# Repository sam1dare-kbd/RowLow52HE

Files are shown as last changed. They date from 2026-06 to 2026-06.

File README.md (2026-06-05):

# RowLow52HE

RowLow52HE is a 50% Hall-effect keyboard based on the [HE60](https://github.com/peppapighs/HE60) project. <br>

RowLow52HEは、HE60プロジェクトをベースにして設計した50%の磁気キーボードです。<br>
<br>

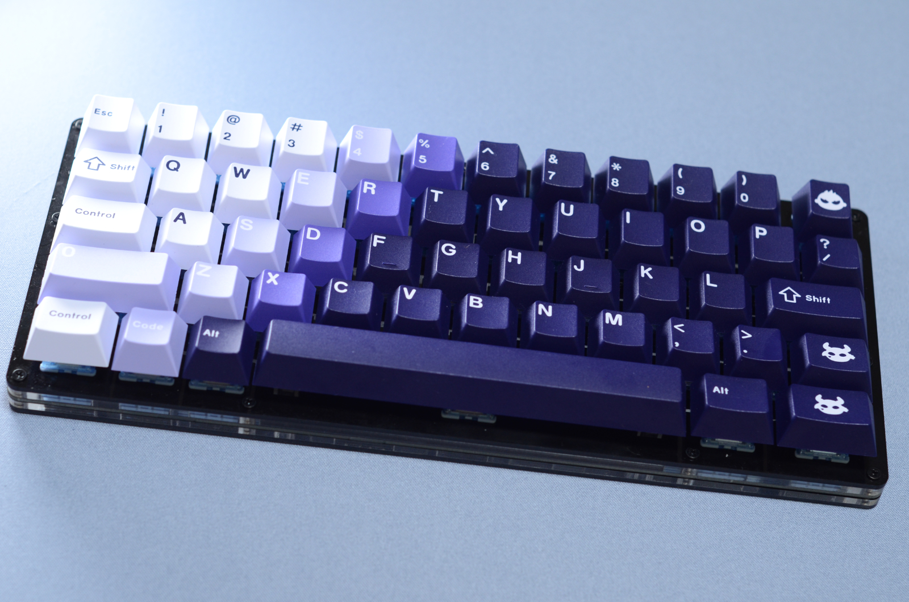
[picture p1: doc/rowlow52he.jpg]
RowLow52HE


---

# Build Guide  

https://note.com/sam1dare/n/naa1372ecf801 <br>
(Japanese text only.)

---

# Important Notes 

This keyboard uses magnetic sensors and may become warm around the MCU during operation. <br>
If you notice abnormal heat generation or unexpected behavior, stop using the device and inspect it before further use.<br><br>

本キーボードは磁気センサーを使用しているため、使用環境によってはMCU周辺が温かくなる場合があります。<br>
異常な発熱や動作不良が発生した場合は、使用を中止してください。

---

# HE60 (Original Project)

Below is the original README from the HE60 project, which this keyboard is based on.

---

# HE60

HE60 is a 60% Hall-effect keyboard PCB with 8kHz polling rate, a split spacebar and Tsangan layout support.

## Features

- Support for GH60 tray mount cases e.g., KBDfans Tofu60 Redux, and KBDfans Holy60.
- Support for gummy O-ring mount cases **if the USB-C port is not soldered** e.g., Bakeneko60, and SingaKBD Unikorn (required 10mm JST cable).
- [libhmk](https://github.com/peppapighs/libhmk) firmware.
- [hmkconf](https://hmk.prasertsuk.com) web-based configurator.

## Disclaimer

- The PCB requires standoffs to be mounted to the switch plate. The mounting points are **not compatible** with other available plates e.g., GEON Venom60 7U plate. HE60 v1 plate **is not compatible** with this PCB.

## Supported Layouts

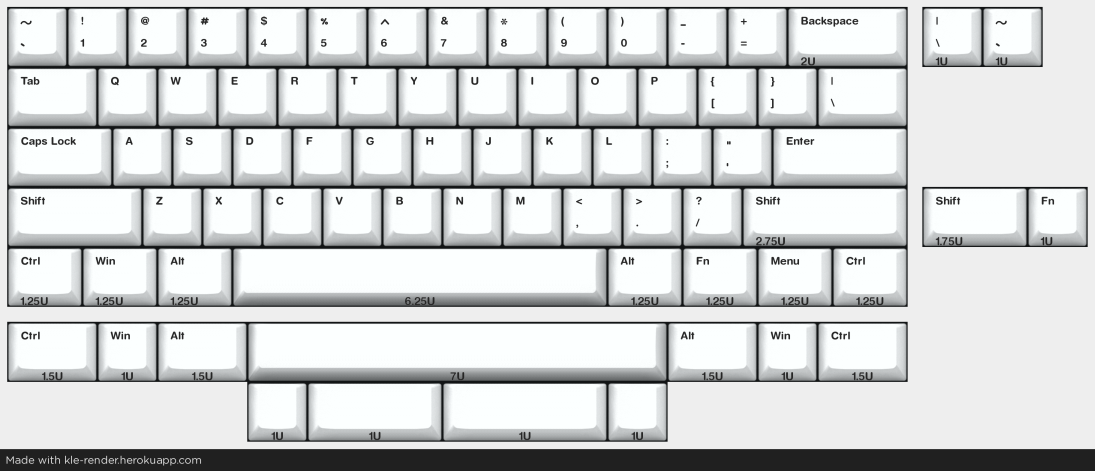
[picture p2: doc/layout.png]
Layouts


## Fabrication

The following files are required:

- BOM (Bill of Materials): Contains the list of components required to build the PCB.
- Pick and Place: Contains the placement of the components on the PCB.
- Gerber: Contains the PCB design files for fabrication.

Note that the components in the BOM are all mounted on the bottom side of the PCB, and are based on the available components in JLCPCB at the time of writing. You may need to adjust the components based on your preference or availability. For the JST connector (labeled `JST_SH`), I used `WAFER-SH1.0-4PWB` offered by JLCPCB. **Make sure to deselect the USB-C port when choosing the components to solder if you are using the gummy O-ring version.**

You may change the Hall-effect sensors during the component selection based on your preference, and availability. Different sensors require different calibration values, which can be adjusted using the web-based configurator. Here are some options that I have used:

- GH39FKSW (Cheapest)
- MT9102ET
- SS39ET
- DRV5055A3
- OH49E-S (Discontinued)

The fabrication files above are available [here](https://github.com/peppapighs/HE60/releases).

## Build Guide

The following items are required to build the PCB:

- PCB
- Switch plate (DXF file available [here](/plate.dxf). You may need to use less flexible materials such as aluminum or FR4 to prevent the switch at the top right corner from popping out if you use the alternative backspace layout. If you would like to manufacture FR4 plate along with the PCB, you can find the GERBER file for the plate [here](https://github.com/peppapighs/HE60/releases).)
- Magnetic switches (e.g., GEON Raw HE, Gateron Magnetic Jade, Duhuk Core HE, etc.)
- Stabilizers (**Clip-in stabilizers are required for the gummy O-ring version**)
- M2 3.5mm standoffs x8
- M2 3mm flat head screws x16

1. Install the stabilizers to the PCB.

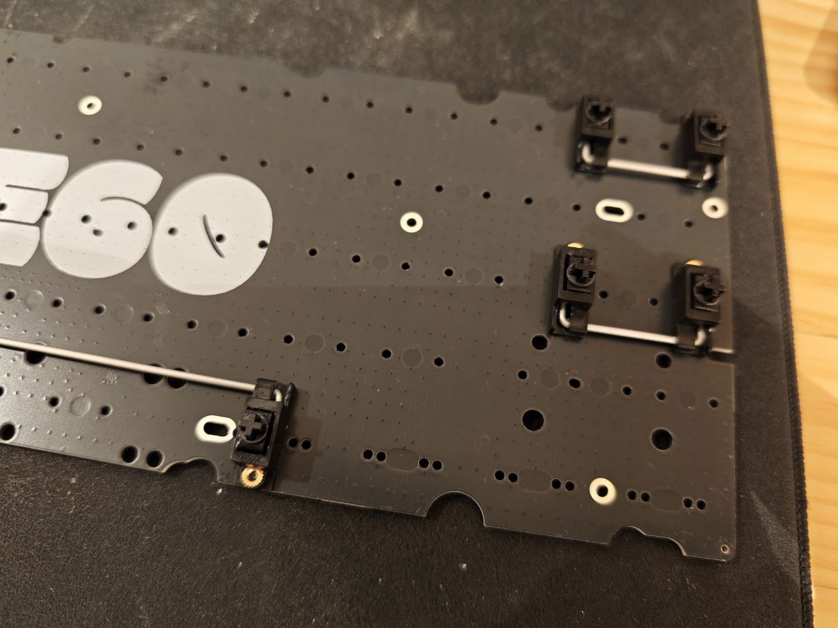
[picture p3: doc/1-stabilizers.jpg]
Stabilizers


2. Attach the standoffs to the PCB using the M2 screws.

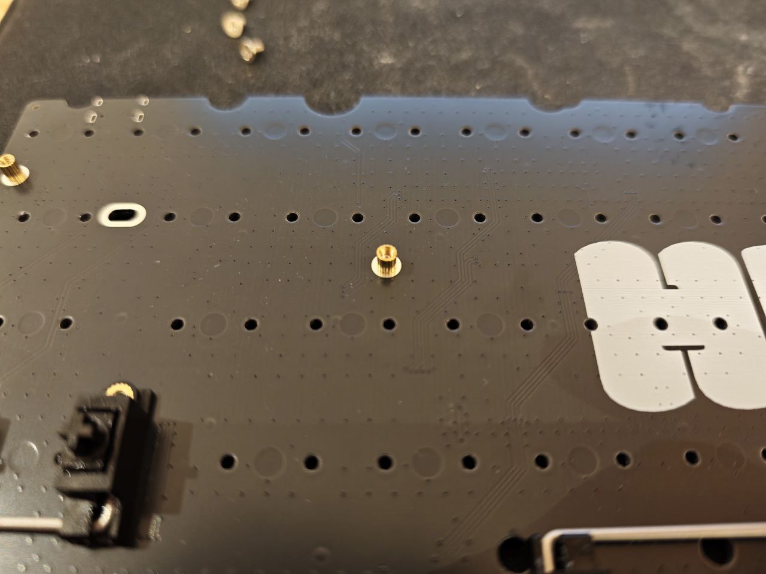
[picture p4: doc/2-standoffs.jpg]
Standoff


3. Install the switches to the plate. Assemble the plate and PCB together. Press the PCB against the plate to make sure the switches are seated properly. Screw the standoffs to the plate using the rest of the M2 screws.

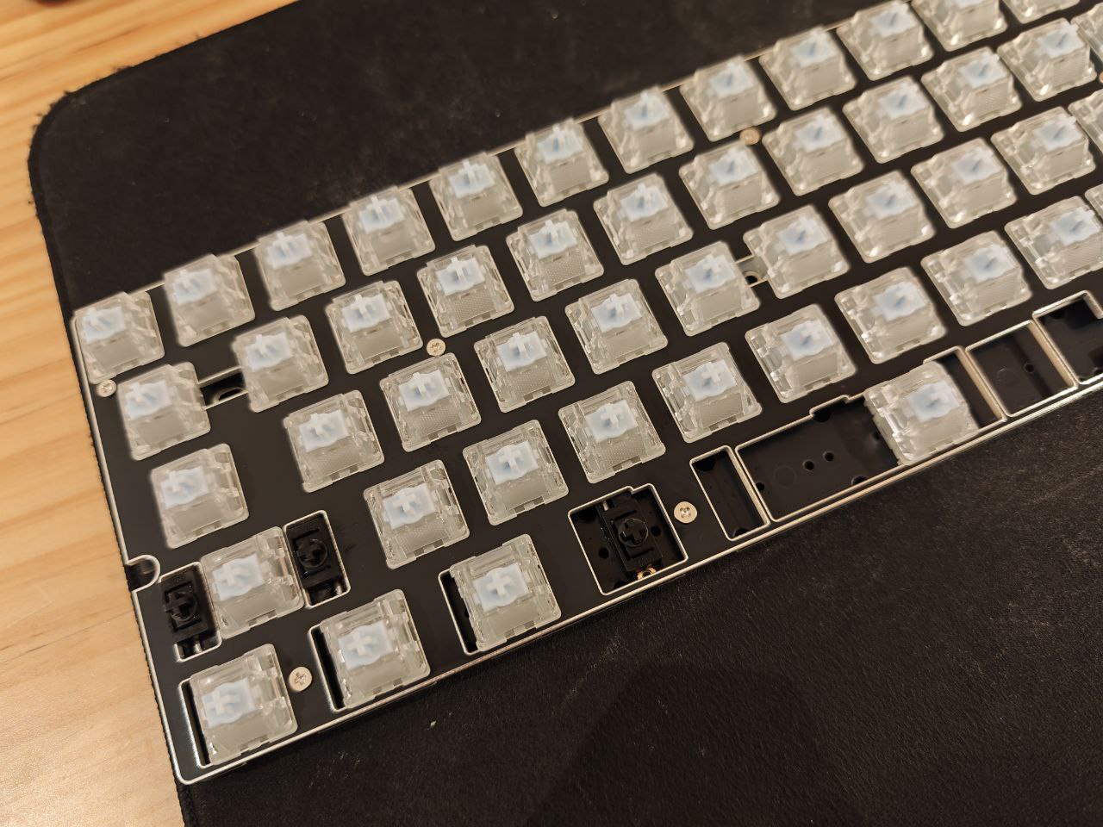
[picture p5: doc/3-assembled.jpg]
Assembled


4. Install the PCB into the case.

Case with keycaps

## Firmware

Head to [libhmk](https://github.com/peppapighs/libhmk/releases) for a pre-compiled firmware. The firmware can be flashed using DFU mode, which can be entered by holding the BOOT button before plugging in. You may need to install the DFU bootloader driver using Zadig. See [libhmk](https://github.com/peppapighs/libhmk) for more information for firmware flashing instructions.

## Acknowledgements

- Xelus from AEBoards for reviewing the PCB design and providing feedback.
- Keyboard Atelier community for supporting the project.

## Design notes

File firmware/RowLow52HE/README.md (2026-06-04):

# RowLowHE52

 RowLowHE52 is a 50% Hall-effect keyboard 

- **Keyboard Maintainer**: [sam1dare-kbd](https://github.com/sam1dare-kbd)
- **Hardware Support**: [sam1dare-kbd/RowLow52HE](https://github.com/sam1dare-kbd/RowLow52HE)

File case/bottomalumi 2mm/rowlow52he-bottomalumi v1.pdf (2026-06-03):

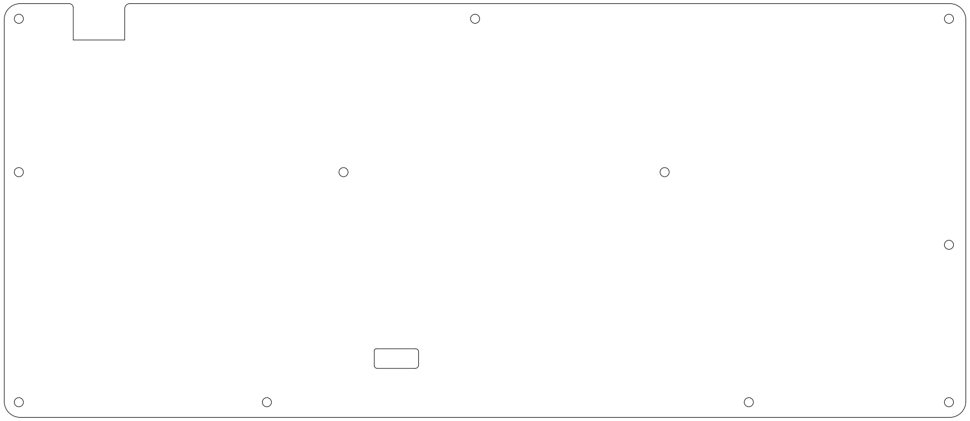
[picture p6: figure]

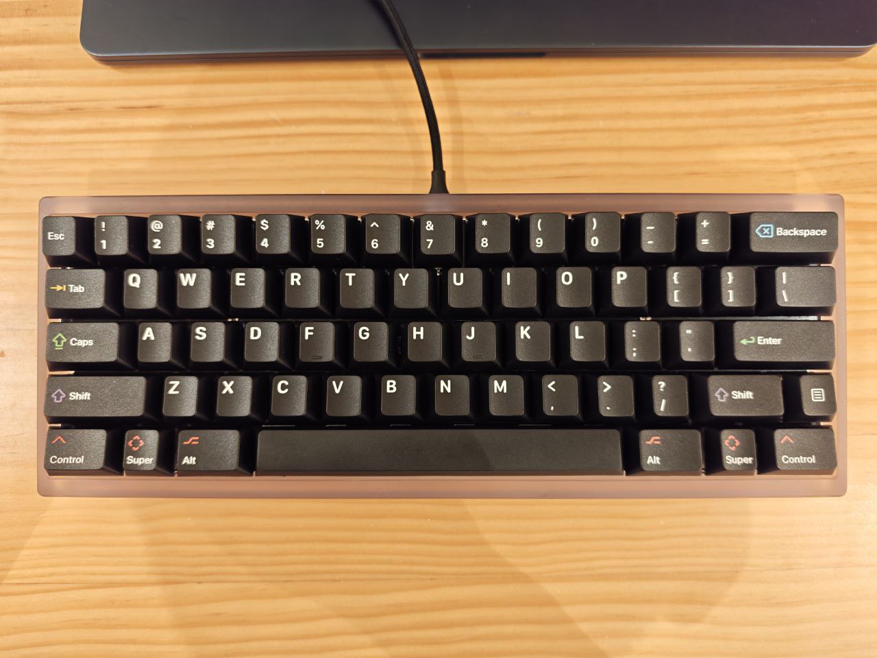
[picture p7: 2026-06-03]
doc/4-complete.jpg

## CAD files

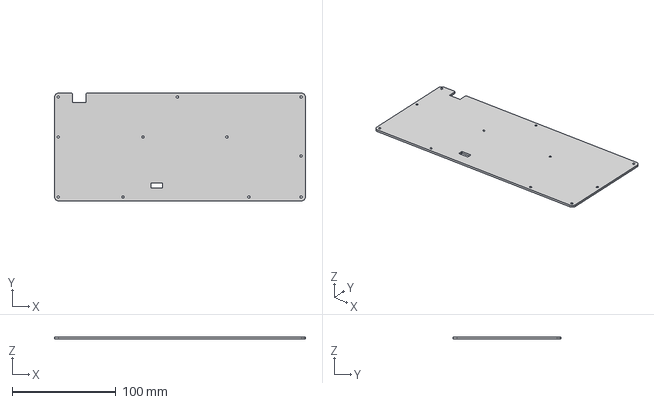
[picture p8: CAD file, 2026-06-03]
case/bottomalumi 2mm/rowlow52he-bottomalumi v1.step
242.2 x 104.1 x 2.00 mm

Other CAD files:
case/bottomalumi 2mm/rowlow52he-bottomalumi v1.f3d
case/bottomalumi 2mm/rowlow52he-bottomalumi v1.stl

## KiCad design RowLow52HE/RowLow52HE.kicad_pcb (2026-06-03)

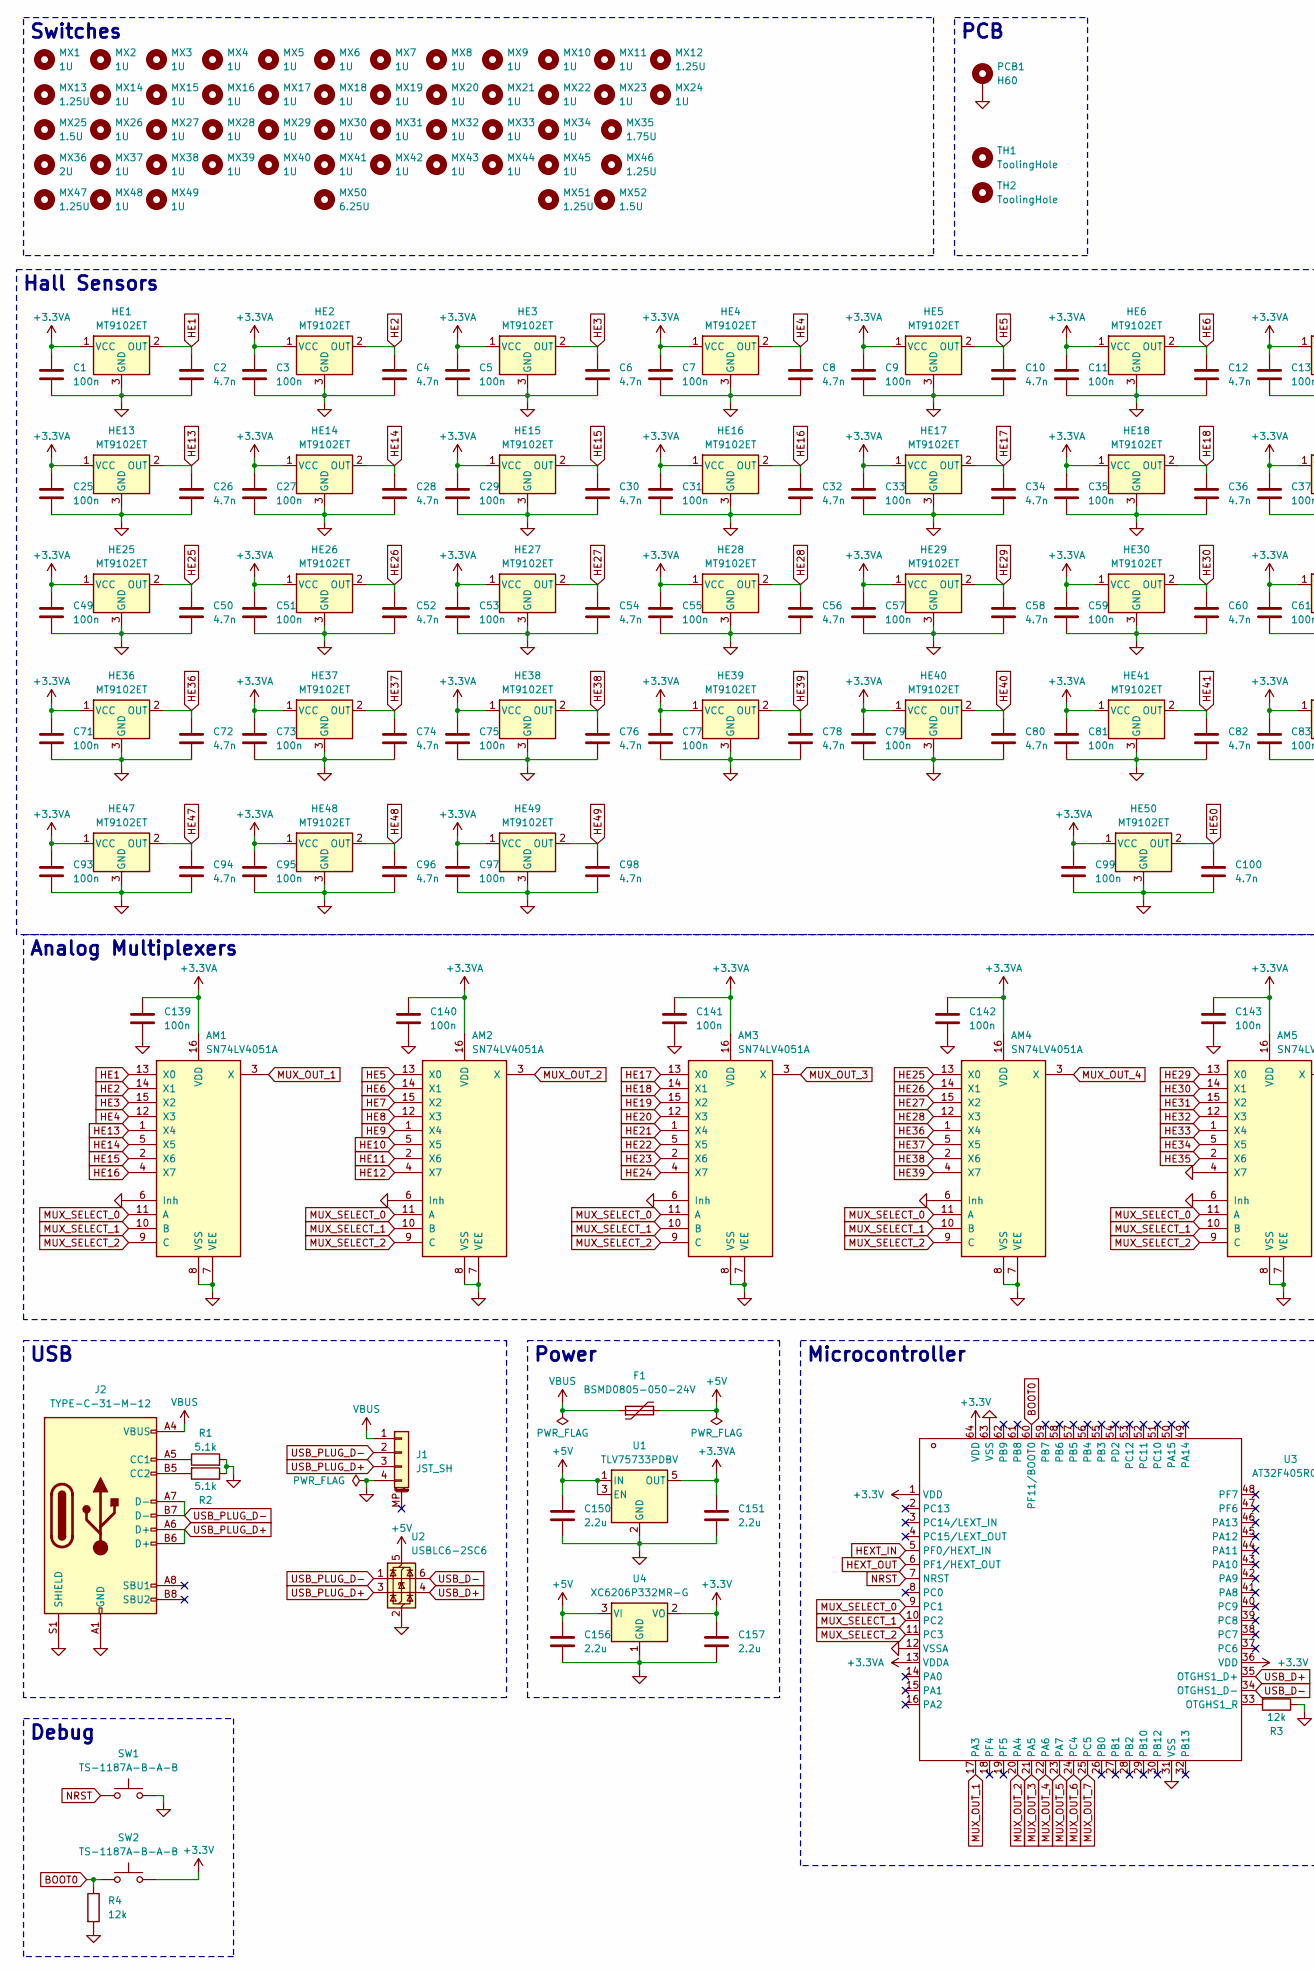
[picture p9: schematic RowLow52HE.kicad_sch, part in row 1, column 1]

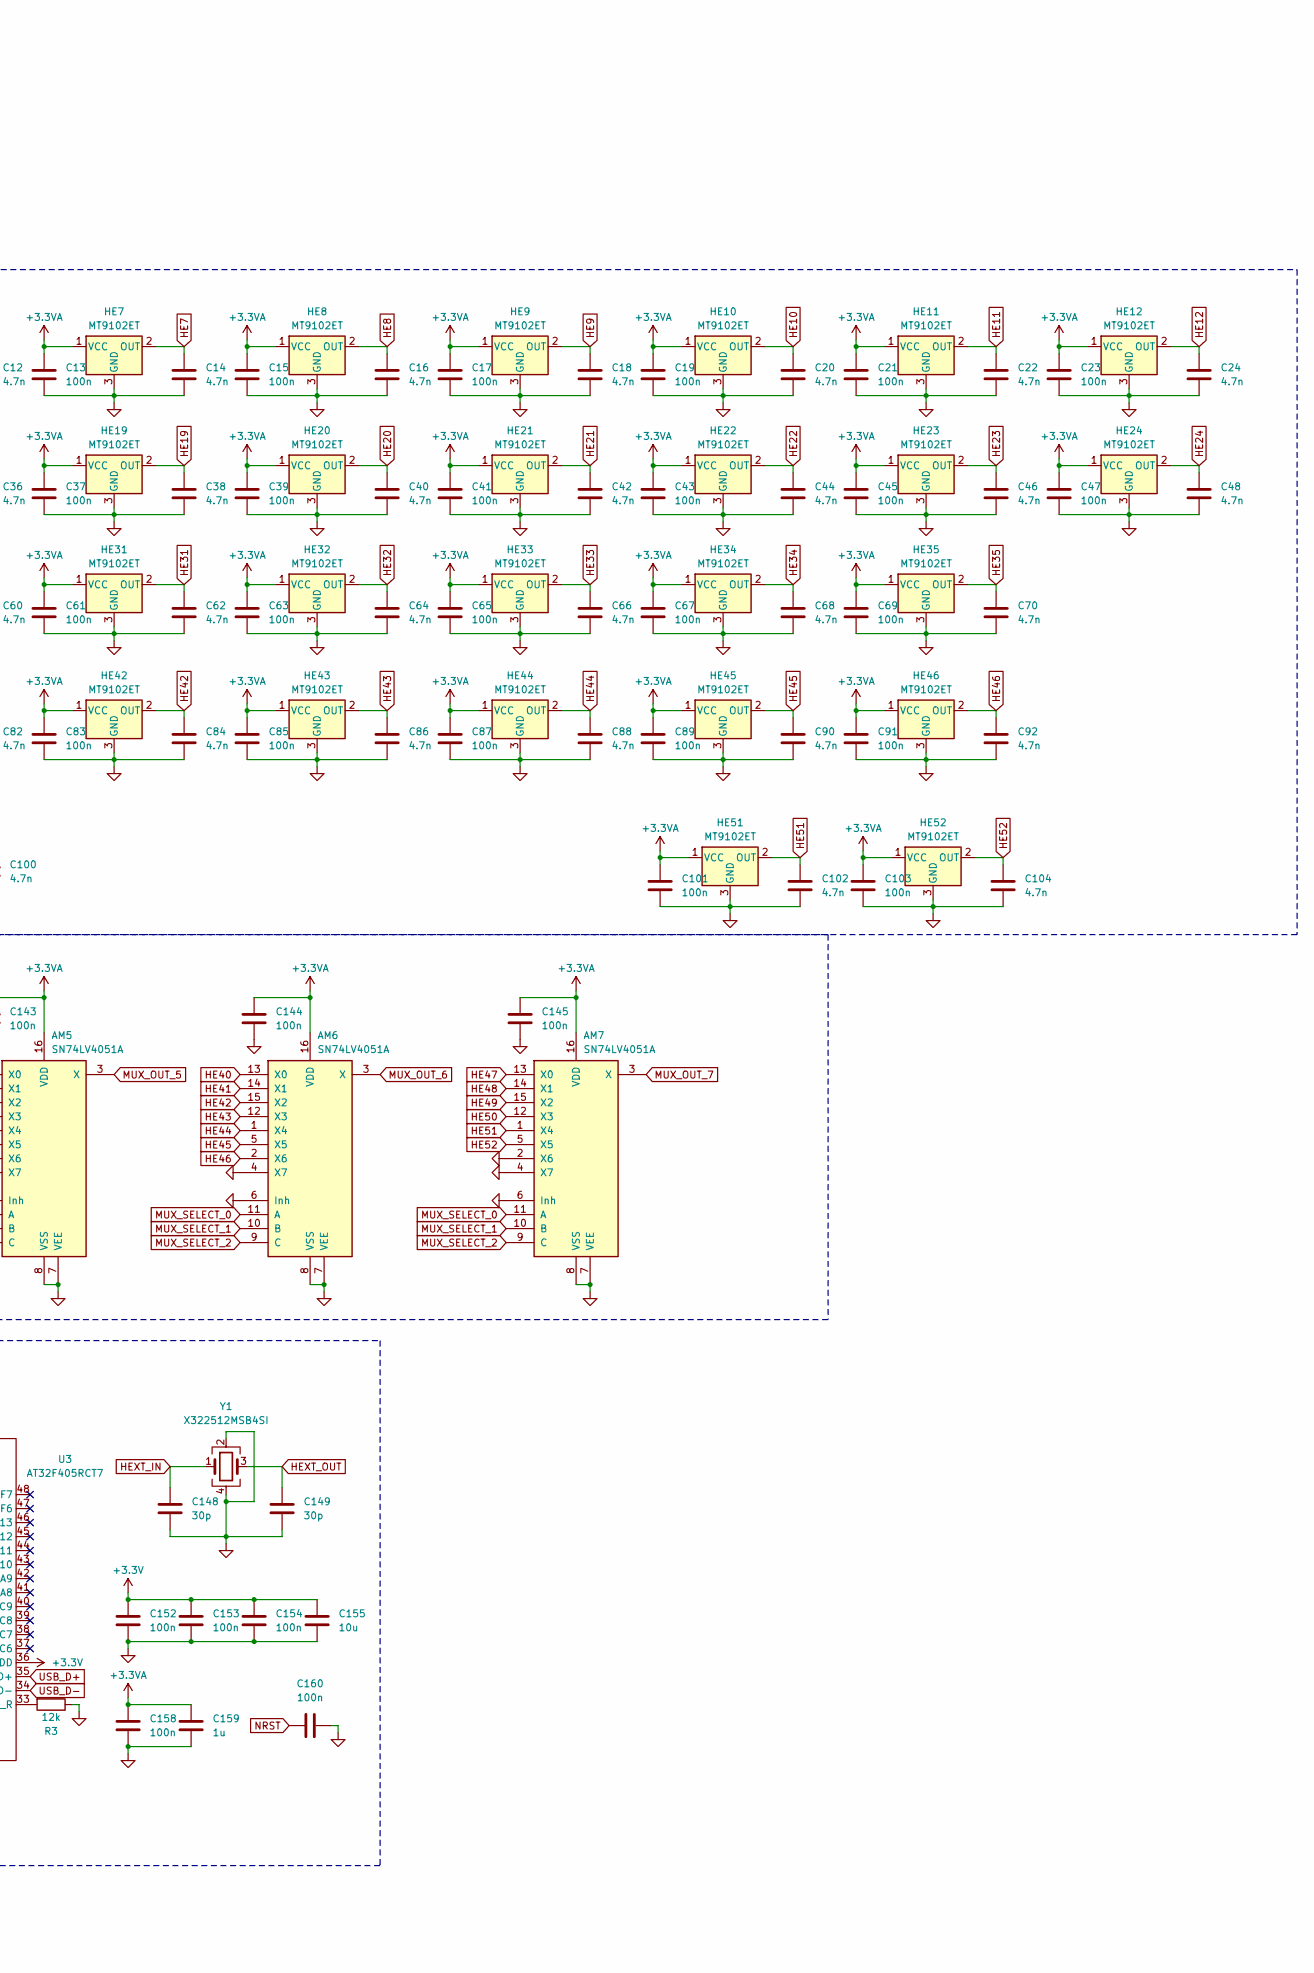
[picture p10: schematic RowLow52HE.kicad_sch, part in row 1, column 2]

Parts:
AM1, AM2, AM3, AM4, AM5, AM6, AM7: SN74LV4051A; TSSOP-16_4.4x5mm_P0.65mm
C1, C3, C5, C7, C9, C11, C13, C15, C17, C19, C21, C23, C25, C27, C29, C31, C33, C35, C37, C39, C41, C43, C45, C47, C49, C51, C53, C55, C57, C59, C61, C63, C65, C67, C69, C71, C73, C75, C77, C79, C81, C83, C85, C87, C89, C91, C93, C95, C97, C99, C101, C103, C139, C140, C141, C142, C143, C144, C145, C152, C153, C154, C158, C160: 100n; C_0402_1005Metric
C2, C4, C6, C8, C10, C12, C14, C16, C18, C20, C22, C24, C26, C28, C30, C32, C34, C36, C38, C40, C42, C44, C46, C48, C50, C52, C54, C56, C58, C60, C62, C64, C66, C68, C70, C72, C74, C76, C78, C80, C82, C84, C86, C88, C90, C92, C94, C96, C98, C100, C102, C104: 4.7n; C_0402_1005Metric
C148, C149: 30p; C_0603_1608Metric
C150, C151, C156, C157: 2.2u; C_0603_1608Metric
C155: 10u; C_0603_1608Metric
C159: 1u; C_0603_1608Metric
F1: BSMD0805-050-24V; Fuse_0805_2012Metric
HE1, HE2, HE3, HE4, HE5, HE6, HE7, HE8, HE9, HE10, HE11, HE12, HE13, HE14, HE15, HE16, HE17, HE18, HE19, HE20, HE21, HE22, HE23, HE24, HE25, HE26, HE27, HE28, HE29, HE30, HE31, HE32, HE33, HE34, HE35, HE36, HE37, HE38, HE39, HE40, HE41, HE42, HE43, HE44, HE45, HE46, HE47, HE48, HE49, HE50, HE51, HE52: MT9102ET; SOT-23-3
J1: JST_SH; JST_SH_SM04B-SRSS-TB_1x04-1MP_P1.00mm_Horizontal
J2: TYPE-C-31-M-12; USB_C_Receptacle_HRO_TYPE-C-31-M-12
MX1, MX2, MX3, MX4, MX5, MX6, MX7, MX8, MX9, MX10, MX11, MX14, MX15, MX16, MX17, MX18, MX19, MX20, MX21, MX22, MX23, MX24, MX26, MX27, MX28, MX29, MX30, MX31, MX32, MX33, MX34, MX37, MX38, MX39, MX40, MX41, MX42, MX43, MX44, MX45, MX48, MX49: 1U; MX-1U
MX12, MX13, MX46, MX47, MX51: 1.25U; MX-1.25U
MX25, MX52: 1.5U; MX-1.5U
MX35: 1.75U; MX-1.75U
MX36: 2U; MX-2U
MX50: 6.25U; MX-6.25U-ReversedStabilizers
PCB1: H60
R1, R2: 5.1k; R_0402_1005Metric
R3, R4: 12k; R_0402_1005Metric
SW1, SW2: TS-1187A-B-A-B; SW_Push_1P1T_XKB_TS-1187A
TH1, TH2: ToolingHole
U1: TLV75733PDBV; SOT-23-5
U2: USBLC6-2SC6; SOT-23-6
U3: AT32F405RCT7; LQFP-64_10x10mm_P0.5mm
U4: XC6206P332MR-G; SOT-23-3
Y1: X322512MSB4SI; Crystal_SMD_3225-4Pin_3.2x2.5mm

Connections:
+3.3V: C152.1, C153.1, C154.1, C155.1, C157.1, SW2.2, U3.1 (VDD), U3.36 (VDD), U3.64 (VDD), U4.2 (VO)
+3.3VA: AM1.16 (VDD), AM2.16 (VDD), AM3.16 (VDD), AM4.16 (VDD), AM5.16 (VDD), AM6.16 (VDD), AM7.16 (VDD), C1.1, C3.1, C5.1, C7.1, C9.1, C11.1, C13.1, C15.1, C17.1, C19.1, C21.1, C23.1, C25.1, C27.1, C29.1, C31.1, C33.1, C35.1, C37.1, C39.1, C41.1, C43.1, C45.1, C47.1, C49.1, C51.1, C53.1, C55.1, C57.1, C59.1, C61.1, C63.1, C65.1, C67.1, C69.1, C71.1, C73.1, C75.1, C77.1, C79.1, C81.1, C83.1, C85.1, C87.1, C89.1, C91.1, C93.1, C95.1, C97.1, C99.1, C101.1, C103.1, C139.1, C140.1, C141.1, C142.1, C143.1, C144.1, C145.1, C151.1, C158.1, C159.1, HE1.1 (VCC), HE2.1 (VCC), HE3.1 (VCC), HE4.1 (VCC), HE5.1 (VCC), HE6.1 (VCC), HE7.1 (VCC), HE8.1 (VCC), HE9.1 (VCC), HE10.1 (VCC), HE11.1 (VCC), HE12.1 (VCC), HE13.1 (VCC), HE14.1 (VCC), HE15.1 (VCC), HE16.1 (VCC), HE17.1 (VCC), HE18.1 (VCC), HE19.1 (VCC), HE20.1 (VCC), HE21.1 (VCC), HE22.1 (VCC), HE23.1 (VCC), HE24.1 (VCC), HE25.1 (VCC), HE26.1 (VCC), HE27.1 (VCC), HE28.1 (VCC), HE29.1 (VCC), HE30.1 (VCC), HE31.1 (VCC), HE32.1 (VCC), HE33.1 (VCC), HE34.1 (VCC), HE35.1 (VCC), HE36.1 (VCC), HE37.1 (VCC), HE38.1 (VCC), HE39.1 (VCC), HE40.1 (VCC), HE41.1 (VCC), HE42.1 (VCC), HE43.1 (VCC), HE44.1 (VCC), HE45.1 (VCC), HE46.1 (VCC), HE47.1 (VCC), HE48.1 (VCC), HE49.1 (VCC), HE50.1 (VCC), HE51.1 (VCC), HE52.1 (VCC), U1.5 (OUT), U3.13 (VDDA)
+5V: C150.1, C156.1, F1.2, U1.1 (IN), U1.3 (EN), U2.5 (VBUS), U4.3 (VI)
BOOT0: R4.1, SW2.1, U3.60 (PF11/BOOT0)
GND: AM1.6 (Inh), AM1.7 (VEE), AM1.8 (VSS), AM2.6 (Inh), AM2.7 (VEE), AM2.8 (VSS), AM3.6 (Inh), AM3.7 (VEE), AM3.8 (VSS), AM4.6 (Inh), AM4.7 (VEE), AM4.8 (VSS), AM5.4 (X7), AM5.6 (Inh), AM5.7 (VEE), AM5.8 (VSS), AM6.4 (X7), AM6.6 (Inh), AM6.7 (VEE), AM6.8 (VSS), AM7.2 (X6), AM7.4 (X7), AM7.6 (Inh), AM7.7 (VEE), AM7.8 (VSS), C1.2, C2.2, C3.2, C4.2, C5.2, C6.2, C7.2, C8.2, C9.2, C10.2, C11.2, C12.2, C13.2, C14.2, C15.2, C16.2, C17.2, C18.2, C19.2, C20.2, C21.2, C22.2, C23.2, C24.2, C25.2, C26.2, C27.2, C28.2, C29.2, C30.2, C31.2, C32.2, C33.2, C34.2, C35.2, C36.2, C37.2, C38.2, C39.2, C40.2, C41.2, C42.2, C43.2, C44.2, C45.2, C46.2, C47.2, C48.2, C49.2, C50.2, C51.2, C52.2, C53.2, C54.2, C55.2, C56.2, C57.2, C58.2, C59.2, C60.2, C61.2, C62.2, C63.2, C64.2, C65.2, C66.2, C67.2, C68.2, C69.2, C70.2, C71.2, C72.2, C73.2, C74.2, C75.2, C76.2, C77.2, C78.2, C79.2, C80.2, C81.2, C82.2, C83.2, C84.2, C85.2, C86.2, C87.2, C88.2, C89.2, C90.2, C91.2, C92.2, C93.2, C94.2, C95.2, C96.2, C97.2, C98.2, C99.2, C100.2, C101.2, C102.2, C103.2, C104.2, C139.2, C140.2, C141.2, C142.2, C143.2, C144.2, C145.2, C148.2, C149.2, C150.2, C151.2, C152.2, C153.2, C154.2, C155.2, C156.2, C157.2, C158.2, C159.2, C160.2, HE1.3 (GND), HE2.3 (GND), HE3.3 (GND), HE4.3 (GND), HE5.3 (GND), HE6.3 (GND), HE7.3 (GND), HE8.3 (GND), HE9.3 (GND), HE10.3 (GND), HE11.3 (GND), HE12.3 (GND), HE13.3 (GND), HE14.3 (GND), HE15.3 (GND), HE16.3 (GND), HE17.3 (GND), HE18.3 (GND), HE19.3 (GND), HE20.3 (GND), HE21.3 (GND), HE22.3 (GND), HE23.3 (GND), HE24.3 (GND), HE25.3 (GND), HE26.3 (GND), HE27.3 (GND), HE28.3 (GND), HE29.3 (GND), HE30.3 (GND), HE31.3 (GND), HE32.3 (GND), HE33.3 (GND), HE34.3 (GND), HE35.3 (GND), HE36.3 (GND), HE37.3 (GND), HE38.3 (GND), HE39.3 (GND), HE40.3 (GND), HE41.3 (GND), HE42.3 (GND), HE43.3 (GND), HE44.3 (GND), HE45.3 (GND), HE46.3 (GND), HE47.3 (GND), HE48.3 (GND), HE49.3 (GND), HE50.3 (GND), HE51.3 (GND), HE52.3 (GND), J1.4, J2.A1 (GND), J2.A12 (GND), J2.B1 (GND), J2.B12 (GND), J2.S1 (SHIELD), PCB1.1, R1.2, R2.1, R3.1, R4.2, SW1.2, U1.2 (GND), U2.2 (GND), U3.12 (VSSA), U3.31 (VSS), U3.63 (VSS), U4.1 (GND), Y1.2, Y1.4
HE1: AM1.13 (X0), C2.1, HE1.2 (OUT)
HE2: AM1.14 (X1), C4.1, HE2.2 (OUT)
HE3: AM1.15 (X2), C6.1, HE3.2 (OUT)
HE4: AM1.12 (X3), C8.1, HE4.2 (OUT)
HE5: AM2.13 (X0), C10.1, HE5.2 (OUT)
HE6: AM2.14 (X1), C12.1, HE6.2 (OUT)
HE7: AM2.15 (X2), C14.1, HE7.2 (OUT)
HE8: AM2.12 (X3), C16.1, HE8.2 (OUT)
HE9: AM2.1 (X4), C18.1, HE9.2 (OUT)
HE10: AM2.5 (X5), C20.1, HE10.2 (OUT)
HE11: AM2.2 (X6), C22.1, HE11.2 (OUT)
HE12: AM2.4 (X7), C24.1, HE12.2 (OUT)
HE13: AM1.1 (X4), C26.1, HE13.2 (OUT)
HE14: AM1.5 (X5), C28.1, HE14.2 (OUT)
HE15: AM1.2 (X6), C30.1, HE15.2 (OUT)
HE16: AM1.4 (X7), C32.1, HE16.2 (OUT)
HE17: AM3.13 (X0), C34.1, HE17.2 (OUT)
HE18: AM3.14 (X1), C36.1, HE18.2 (OUT)
HE19: AM3.15 (X2), C38.1, HE19.2 (OUT)
HE20: AM3.12 (X3), C40.1, HE20.2 (OUT)
HE21: AM3.1 (X4), C42.1, HE21.2 (OUT)
HE22: AM3.5 (X5), C44.1, HE22.2 (OUT)
HE23: AM3.2 (X6), C46.1, HE23.2 (OUT)
HE24: AM3.4 (X7), C48.1, HE24.2 (OUT)
HE25: AM4.13 (X0), C50.1, HE25.2 (OUT)
HE26: AM4.14 (X1), C52.1, HE26.2 (OUT)
HE27: AM4.15 (X2), C54.1, HE27.2 (OUT)
HE28: AM4.12 (X3), C56.1, HE28.2 (OUT)
HE29: AM5.13 (X0), C58.1, HE29.2 (OUT)
HE30: AM5.14 (X1), C60.1, HE30.2 (OUT)
HE31: AM5.15 (X2), C62.1, HE31.2 (OUT)
HE32: AM5.12 (X3), C64.1, HE32.2 (OUT)
HE33: AM5.1 (X4), C66.1, HE33.2 (OUT)
HE34: AM5.5 (X5), C68.1, HE34.2 (OUT)
HE35: AM5.2 (X6), C70.1, HE35.2 (OUT)
HE36: AM4.1 (X4), C72.1, HE36.2 (OUT)
HE37: AM4.5 (X5), C74.1, HE37.2 (OUT)
HE38: AM4.2 (X6), C76.1, HE38.2 (OUT)
HE39: AM4.4 (X7), C78.1, HE39.2 (OUT)
HE40: AM6.13 (X0), C80.1, HE40.2 (OUT)
HE41: AM6.14 (X1), C82.1, HE41.2 (OUT)
HE42: AM6.15 (X2), C84.1, HE42.2 (OUT)
HE43: AM6.12 (X3), C86.1, HE43.2 (OUT)
HE44: AM6.1 (X4), C88.1, HE44.2 (OUT)
HE45: AM6.5 (X5), C90.1, HE45.2 (OUT)
HE46: AM6.2 (X6), C92.1, HE46.2 (OUT)
HE47: AM7.13 (X0), C94.1, HE47.2 (OUT)
HE48: AM7.14 (X1), C96.1, HE48.2 (OUT)
HE49: AM7.15 (X2), C98.1, HE49.2 (OUT)
HE50: AM7.12 (X3), C100.1, HE50.2 (OUT)
HE51: AM7.1 (X4), C102.1, HE51.2 (OUT)
HE52: AM7.5 (X5), C104.1, HE52.2 (OUT)
HEXT_IN: C148.1, U3.5 (PF0/HEXT_IN), Y1.1
HEXT_OUT: C149.1, U3.6 (PF1/HEXT_OUT), Y1.3
MUX_OUT_1: AM1.3 (X), U3.17 (PA3)
MUX_OUT_2: AM2.3 (X), U3.20 (PA4)
MUX_OUT_3: AM3.3 (X), U3.21 (PA5)
MUX_OUT_4: AM4.3 (X), U3.22 (PA6)
MUX_OUT_5: AM5.3 (X), U3.23 (PA7)
MUX_OUT_6: AM6.3 (X), U3.24 (PC4)
MUX_OUT_7: AM7.3 (X), U3.25 (PC5)
MUX_SELECT_0: AM1.11 (A), AM2.11 (A), AM3.11 (A), AM4.11 (A), AM5.11 (A), AM6.11 (A), AM7.11 (A), U3.9 (PC1)
MUX_SELECT_1: AM1.10 (B), AM2.10 (B), AM3.10 (B), AM4.10 (B), AM5.10 (B), AM6.10 (B), AM7.10 (B), U3.10 (PC2)
MUX_SELECT_2: AM1.9 (C), AM2.9 (C), AM3.9 (C), AM4.9 (C), AM5.9 (C), AM6.9 (C), AM7.9 (C), U3.11 (PC3)
NRST: C160.1, SW1.1, U3.7 (NRST)
unnamed: J2.A5 (CC1), R1.1
unnamed: J2.B5 (CC2), R2.2
unnamed: R3.2, U3.33 (OTGHS1_R)
USB_D+: U2.4 (I/O2), U3.35 (OTGHS1_D+)
USB_D-: U2.6 (I/O1), U3.34 (OTGHS1_D-)
USB_PLUG_D+: J1.3, J2.A6 (D+), J2.B6 (D+), U2.3 (I/O2)
USB_PLUG_D-: J1.2, J2.A7 (D-), J2.B7 (D-), U2.1 (I/O1)
VBUS: F1.1, J1.1, J2.A4 (VBUS), J2.A9 (VBUS), J2.B4 (VBUS), J2.B9 (VBUS)

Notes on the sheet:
PCB
Hall Sensors
Switches
USB
Analog Multiplexers
Power
Debug
Microcontroller

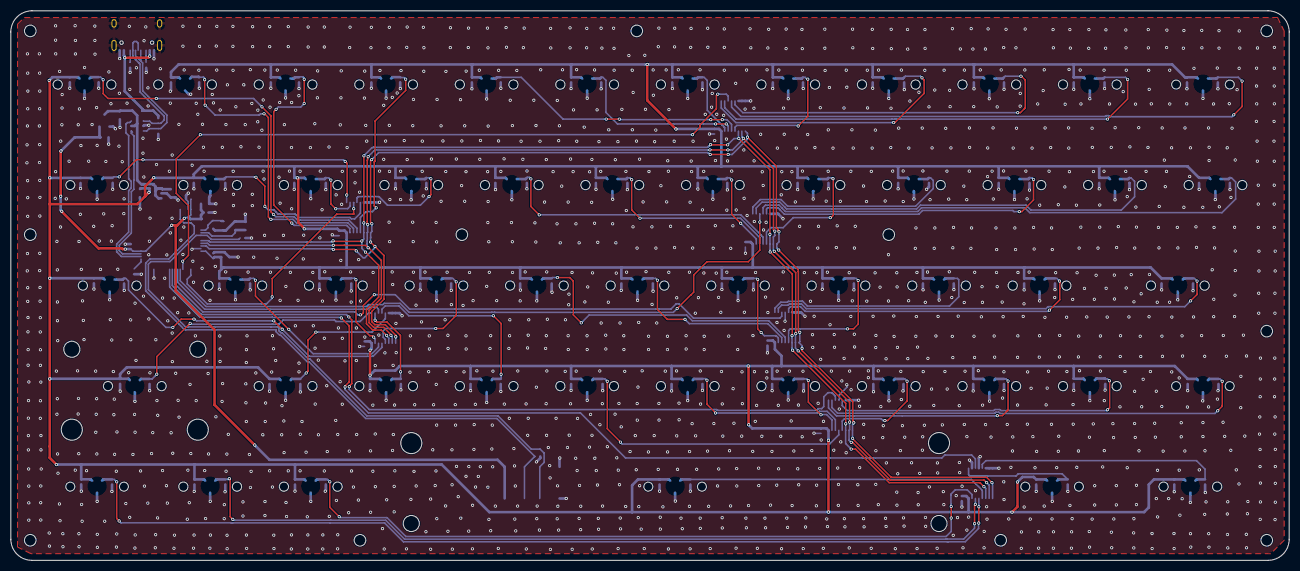
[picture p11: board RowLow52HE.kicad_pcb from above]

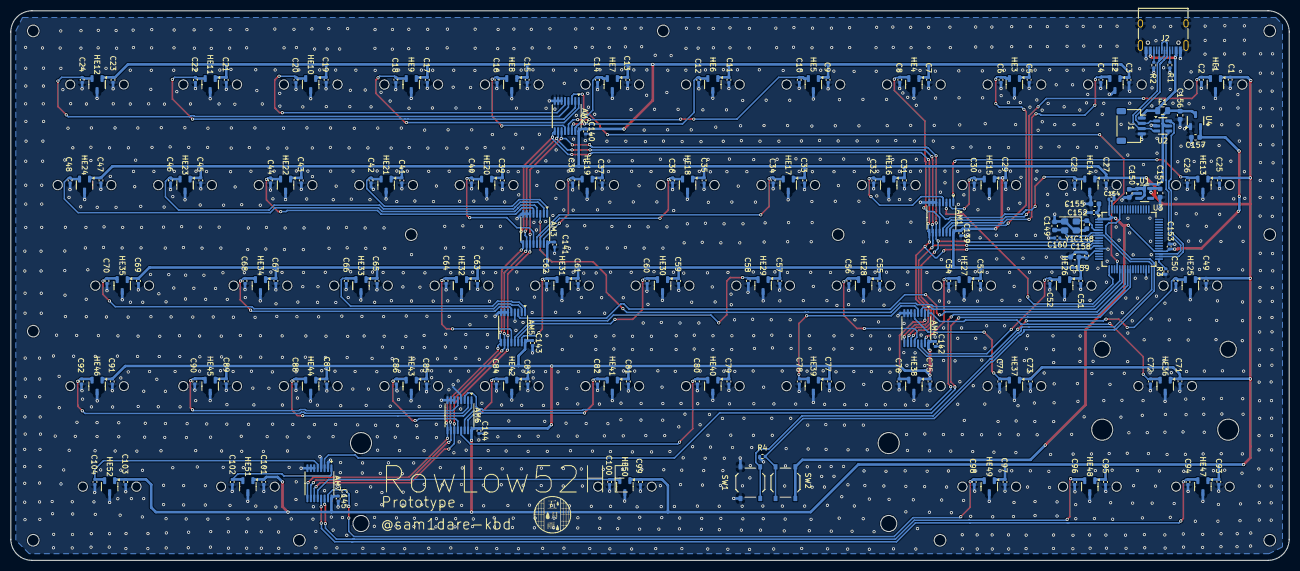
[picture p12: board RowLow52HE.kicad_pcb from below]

Board: 2 copper layers, 242.2 x 104.1 mm, 260 parts (197 on the bottom side), 78 nets.

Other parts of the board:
Ref**: Val**; m2_Screw_Hole
Ref**#2, Ref**#3, Ref**#4, Ref**#5, Ref**#6, Ref**#7, Ref**#8, Ref**#9, Ref**#10, Ref**#11: Val**; m2_Screw_Hole
